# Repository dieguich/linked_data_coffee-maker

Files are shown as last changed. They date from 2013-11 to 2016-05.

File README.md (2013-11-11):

linked_data_coffee-maker
========================

This is a project related to the design of a coffee maker which is able to sense its energy data and to store the breakdown of it in a remote Database as RDF triples. 

Dependencies
-------------

This project has some external dependencies. All of them are stored in other github repositories:

	*  RTClib:     https://github.com/adafruit/RTClib
	*  EmonLib:    https://github.com/openenergymonitor/EmonLib
	*  RestClient: https://github.com/csquared/arduino-restclient
		- This library has been slightly modified, so please use the version which is provided in this github repository.

To add them to you Arduino IDE you have two options: 
	- Either you store them in the libraries folder within the place where you installed the Arduino application; 
	- Either you store them in a folder also called libraries within your Sketchbokk folder.

For more info about new libraries and how to do use of them (dependig of your OS), please follow the next link: http://arduino.cc/en/Guide/Libraries

Thanks a lot to the people who contributes developing libraries like those which are used in this project.

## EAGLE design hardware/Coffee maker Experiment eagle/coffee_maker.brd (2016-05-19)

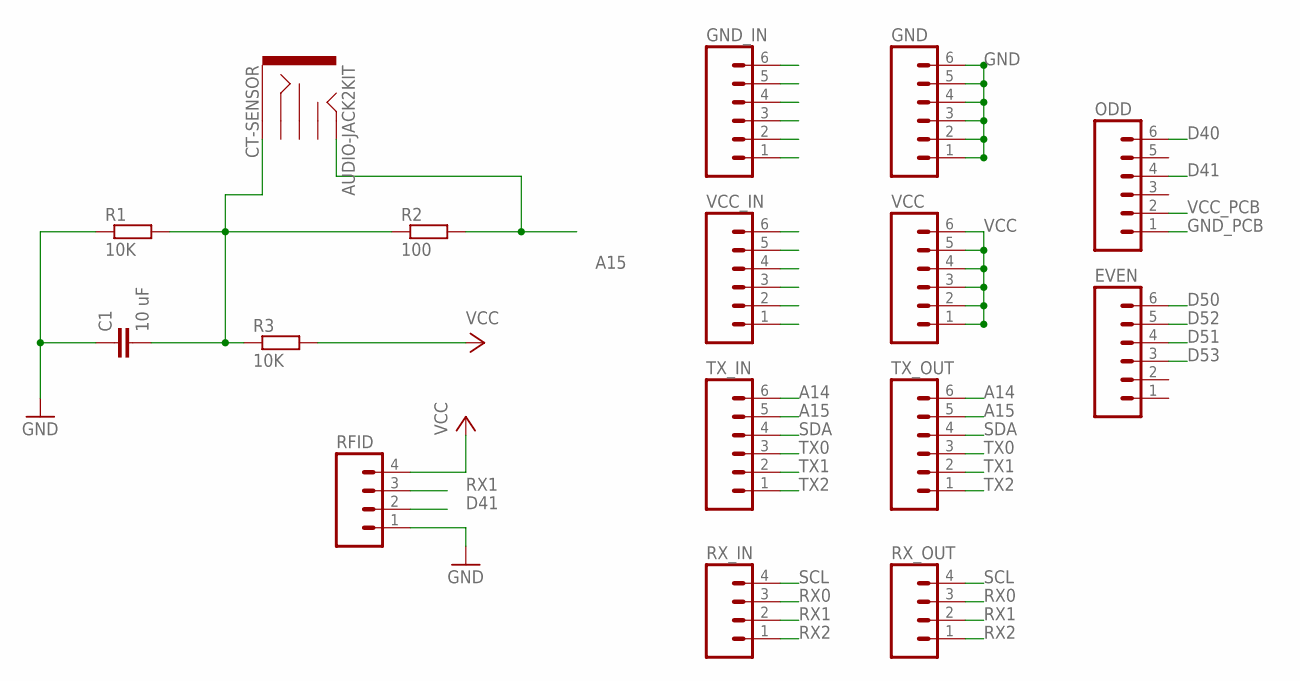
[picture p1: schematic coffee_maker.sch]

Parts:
C1: 10 uF; C1206
CT-SENSOR: AUDIO-JACK2KIT; AUDIO-JACK-KIT
EVEN: M06SIP; 1X06
GND: M06SIP; 1X06
GND_IN: M06SIP; 1X06
ODD: M06SIP; 1X06
R1, R3: 10K; M1206
R2: 100; M1206
RFID: M04SMD2; 1X04-1MM-RA
RX_IN: M04PTH; 1X04
RX_OUT: M04PTH; 1X04
TX_IN: M06SIP; 1X06
TX_OUT: M06SIP; 1X06
VCC: M06SIP; 1X06
VCC_IN: M06SIP; 1X06

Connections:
A14: TX_IN.6, TX_OUT.6
A15: CT-SENSOR.TIP, R2.2, TX_IN.5, TX_OUT.5
D40: ODD.6
D41: ODD.4, RFID.2
D50: EVEN.6
D51: EVEN.4
D52: EVEN.5
D53: EVEN.3
GND: C1.1, GND.1, GND.2, GND.3, GND.4, GND.5, GND.6, GND_IN.6, R1.1, RFID.1
GND_PCB: ODD.1
unnamed: C1.2, CT-SENSOR.SLEEVE, R1.2, R2.1, R3.1
RX0: RX_IN.3, RX_OUT.3
RX1: RFID.3, RX_IN.2, RX_OUT.2
RX2: RX_IN.1, RX_OUT.1
SCL: RX_IN.4, RX_OUT.4
SDA: TX_IN.4, TX_OUT.4
TX0: TX_IN.3, TX_OUT.3
TX1: TX_IN.2, TX_OUT.2
TX2: TX_IN.1, TX_OUT.1
VCC: R3.2, RFID.4, VCC.1, VCC.2, VCC.3, VCC.4, VCC.5, VCC.6, VCC_IN.1
VCC_PCB: ODD.2

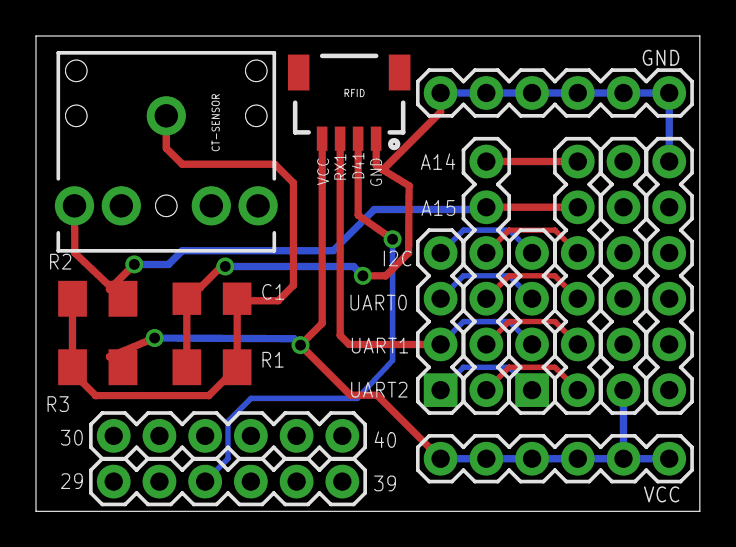
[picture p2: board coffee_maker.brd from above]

Board: 2 copper layers, 36.9 x 26.4 mm, 16 parts (0 on the bottom side), 14 nets.

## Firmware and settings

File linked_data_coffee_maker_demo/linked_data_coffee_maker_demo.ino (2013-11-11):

#include <avr/pgmspace.h>
#include <avr/wdt.h> 
#include <Udp.h>
#include <RTClib.h>
#include <string.h>

#include <SPI.h>
#include <Ethernet.h>
#include <EEPROM.h>
#include <Wire.h>
#include "RestClient.h"
#include "EmonLib.h"
#include "includes.h"

/*  Current */
uint8_t        currentMeasurePin = A1;    // pin to measure the current flow
uint8_t        buttonState       = 0;

/* Time working */
unsigned long currentTime        = 0;        //  to store the current UnixTime in each loop iteration (base: UnixTime + time consumed)
boolean       isStable           = false;

/* Enter a MAC address and IP address for your controller below.
 The IP address will be dependent on your local network:*/
 
/****** TO FILL ******
 ****** ------- ******/
byte mac[]     = {  };  // Type your MAC address inside the curly brackets as following : 0x90, 0xA2, 0xDA, 0x0E, 0x94, 0x69 

/****** TO FILL ******
 ****** ------- ******/
#if STATIC_IP_ADDRESS  
  IPAddress dnsServer(138, 100, 52, 102); // Type your DNS address  inside the brackets as following :    138, 100, 52, 102
  IPAddress gateway(138, 100, 52, 102);   // Type your GATEWAY address inside the brackets as following : 192, 168, 52, 101
  IPAddress netmask(138, 100, 52, 102); // Type your NETMASK address inside the brackets as following :   255, 255, 255, 0
  IPAddress ip(138, 100, 52, 102);      // Type your IP address inside the brackets as following :        192, 168, 52, 102
#endif

/*Related with NTP server and UDP setup for TxRx */
unsigned long UnixTime          = 0;           // variable to store the Unix NTP time retrieved form NTP server
unsigned long referenceUnixTime = 0;           // variable to store the reference Unix NTP time stored in EEPROM (0)

/****** TO FILL ******
 ****** ------- ******/
IPAddress timeServer(129, 6, 15, 28);            // By default Nist server. If you prefer a different UTP server (local or country) change it e.g.: 129, 6, 15, 28


byte pb[NTP_PACKET_SIZE];                      // buffer to hold incoming and outgoing packets 
EthernetUDP Udp;                               // A UDP instance to let us send and receive packets over UDP


EnergyMonitor emonInstance;                    // A emonLib instance to read current Values fron current CT sensor
RestClient client = RestClient(IP_DB_SERVER, PORT_DB_SERVER);  //Rest Client 

/*Energy counters*/
float eCoffees    = 0.0;     // energy Consumption making coffees
float ePeaks      = 0.0;     // energy Consumption by Peaks
float eStartTimes = 0.0;     // energy Consumption by Start Times

/* Counters */
uint8_t nSTimes      = 0;           // number of Start Time peaks per day
uint8_t nCoffees     = 0;           // number of coffees per day
uint8_t nSByPeaks    = 0;           // number of stand by peaks per day
uint8_t nLoopPower   = 0;           // iteration variable


/* Time working */
unsigned long referenceInMillis = 0;        // to store the time stamp when the Energy post was done
unsigned long timeOn            = 0;        // the time that the coffee machine was operating (One hot drink!)
unsigned int  nDays             = 0;        //  number of days the Arduino is active retrying data.


/* Testers */
boolean isStartTime   = false;   // to know if the detected peak belong to [StartTime or Stand-by]
boolean prevWasCoffee = false;   // test if the last peak was a coffe (to distinguish between coffee and peak)
boolean wasOff        = true;    // test if the coffe maker was previously switch off.
boolean isFirstDay    = true;    // variable to know if it's the first day

/*Energy counters*/
float auxEnergy   = 0.0;     // aux to obtain an Energy Consumption making coffees

/* Time working */
unsigned long countStart        = 0;        // to count when a peak has started

/* NoSQL DataBase */
String response   = "";
char   postData[400];
char   buffer[30];
char   consumptionSecsDB[10]; 
char   consumptionTypeDB[20];

/* RFID tags */
char tagValue[10];
long timeRfidDetected = 0;


/* LEDs to know the status */
uint8_t readyPin = 7;
uint8_t postPin  = 3;

/**********
  SETUP
***********/
void setup() {
   
   Serial3.begin(9600);
   wdt_disable(); 
#if ECHO_TO_SERIAL  
   Serial.begin(9600); 
   Serial.println("Start");
#endif
    
    pinMode(readyPin, OUTPUT);
    pinMode(postPin,  OUTPUT);
    pinMode(currentMeasurePin, INPUT);                    // sets the analog pin as input (current measure throug the coffe machine plug -mains)*/    
    digitalWrite(readyPin,  LOW);
    digitalWrite(postPin,   LOW);    
   
   #if STATIC_IP_ADDRESS 
     Ethernet.begin(mac, ip, dnsServer, gateway, netmask);  
   #else
     Ethernet.begin(mac);  
   #endif
   delay(100);
   
   getUnixTime();
#if ECHO_TO_SERIAL  
  Serial.println(Ethernet.localIP()); 
  Serial.print("UnixTime provided by the UTP: ");  
  Serial.println(UnixTime);
  Serial.print("UnixTime converted in human readable time: ");    
  Serial.println(printDateTime(UnixTime));
#endif 

  referenceUnixTime = UnixTime;
  
#if ECHO_TO_SERIAL  
   Serial.println("Working");
#endif
  
  emonInstance.current(currentMeasurePin, CALIBRATION); // sets the Pin from and the calibration to read current Values.
  referenceInMillis = millis();                         // timeStamp to know when the current program start.
  wdt_enable(WDTO_8S);
  
  digitalWrite(readyPin, HIGH);
}

/***********
  LOOP
************/
void loop() {
   
  wdt_reset(); 
  currentTime = UnixTime + ((millis()-referenceInMillis)/1000);
  delay(25);
  
  float currentToMeasure = emonInstance.calcIrms(EMON_INSTANCE_VALUE);
  if (isStable == false && currentToMeasure < 0.1){
    isStable = true;
  }
  if (isStable){
   controlCoffeMade(currentToMeasure); // to read the the RMS current flow [0..30A]
   if (Serial3.available() > 0) {
     rfidReadMug();
   }
   else if(!prevWasCoffee && (millis() > timeRfidDetected + 120000)){
     memset(tagValue, '\0', 10);
   }
  }
}

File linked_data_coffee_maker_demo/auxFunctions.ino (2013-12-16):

/**
  calls the function to show and compute consumptions

**/

void accumulatedEnergyByPeak(){
  
  switch (setType()){
    case 1:{
      eCoffees += (auxEnergy/nLoopPower)*(timeOn/3600000.0);
  #if ECHO_TO_SERIAL                                             
      Serial.print("Consumed by Coffees: ");
      Serial.println(eCoffees, 2);
  #endif                    
      break;
    }
    case 2:{      
      eStartTimes += (auxEnergy/nLoopPower)*(timeOn/3600000.0);
  #if ECHO_TO_SERIAL                                                         
      Serial.print("Consumed by S. time: ");
      Serial.println(eStartTimes, 2);
  #endif            
      break;
    }
    case 3:{
      ePeaks += (auxEnergy/nLoopPower)*(timeOn/3600000.0);
  #if ECHO_TO_SERIAL                                                         
      Serial.print("Consumed by Peaks: ");
      Serial.println(ePeaks, 2);
  #endif            
      break;
    }
    //default: Serial.println("No type");
  }    
}



/**
  This function is many fold:
    * It figures out if the detected activation is a Stand By Peak, a Start Time or a Coffee.
    * Print this information in Serial output if DEBUG mode activated and to currentFile.
    * Before return the current Type, it prints the time implied in each of the detected activation.
**/
int setType(){

  uint8_t nType = 0;

  if(isStartTime){
    if(wasOff){
      wasOff = false;
      nSTimes++;
      prevWasCoffee = false;        
      nType = 2;           
      prinFromMemorySerial(sTime);         
    }
    else if(millis() < countStart){
      if(timeOn > 12000){    
        prinFromMemorySerial(coffee);
        nCoffees++;
        prevWasCoffee = true;
        isStartTime = false;
        nType = 1;
      }else{  
        prinFromMemorySerial(sTime);               
        nSTimes++;
        prevWasCoffee = false;        
        nType = 2;
      }
    }
    else{
      isStartTime = false;
      if(timeOn > 7000 && !prevWasCoffee){
        prinFromMemorySerial(coffee);
        prevWasCoffee = true;
        nCoffees++;
        nType = 1;         
      }else{      
        prinFromMemorySerial(peak);   
        nSByPeaks++;
        prevWasCoffee = false;        
        nType = 3;
      }
    }
  }
  else if(timeOn > 7000){  // if the operating time is bigger than 7secs is a coffee REMOVED:  && !prevWasCoffee
    prinFromMemorySerial(coffee);
    prevWasCoffee = true;    
    nCoffees++;
    nType = 1;
  }
  else{
    prinFromMemorySerial(peak);
    nSByPeaks++;
    prevWasCoffee = false;            
    nType = 3;
  }
  memset(consumptionSecsDB, '\0', 10);
  floatToString(consumptionSecsDB, (timeOn/1000.0), 2, 3);
#if ECHO_TO_SERIAL
  Serial.print(timeOn);
  Serial.print('|');    
#endif

 return nType;
}

/**
  Function to print error to the Serial output (if DEBUG mode is activated).
  Also sets a led to HIGH if an error has been triggered
**/
void error(char *str)
{
#if ECHO_TO_SERIAL    
  Serial.print("error: ");
  Serial.println(str);
#endif   
  delay(500);  
}

/**
  float to string conversion function that runs standalone
**/
char * floatToString(char * outstr, double val, byte precision, byte widthp){
  char temp[16];
  byte i;

  // compute the rounding factor and fractional multiplier
  double roundingFactor = 0.5;
  unsigned long mult = 1;
  for (i = 0; i < precision; i++)
  {
    roundingFactor /= 10.0;
    mult *= 10;
  }
  
  temp[0]='\0';
  outstr[0]='\0';

  if(val < 0.0){
    strcpy(outstr,"-\0");
    val = -val;
  }

  val += roundingFactor;

  strcat(outstr, itoa(int(val),temp,10));  //prints the int part
  if( precision > 0) {
    strcat(outstr, ".\0"); // print the decimal point
    unsigned long frac;
    unsigned long mult = 1;
    byte padding = precision -1;
    while(precision--)
      mult *=10;

    if(val >= 0)
      frac = (val - int(val)) * mult;
    else
      frac = (int(val)- val ) * mult;
    unsigned long frac1 = frac;

    while(frac1 /= 10)
      padding--;

    while(padding--)
      strcat(outstr,"0\0");

    strcat(outstr,itoa(frac,temp,10));
  }

  // generate space padding
  if ((widthp != 0)&&(widthp >= strlen(outstr))){
    byte J=0;
    J = widthp - strlen(outstr);
    
    for (i=0; i< J; i++) {
      temp[i] = ' ';
    }

    temp[i++] = '\0';
    strcat(temp,outstr);
    strcpy(outstr,temp);
  }
  return outstr;
} 

/*****
CouchDB
*****/
void POSTrequest(char* deviceID, char* device_type, char* date, char* timeSecs, char* consumption_type, char* consumption_time_in_secs, char* energy_consumption_Wh, char* coffeeMugID){

    memset(postData, '\0', 400);
    strcpy_P(buffer, (char*)pgm_read_word(&(json_properties[0])));
    strcat(postData, buffer);
    strcat(postData, deviceID);
    strcpy_P(buffer, (char*)pgm_read_word(&(json_properties[1])));
    strcat(postData, buffer);
    strcat(postData, device_type);
    strcpy_P(buffer, (char*)pgm_read_word(&(json_properties[2])));
    strcat(postData, buffer);
    strcat(postData, date);
    strcpy_P(buffer, (char*)pgm_read_word(&(json_properties[3])));
    strcat(postData, buffer);
    strcat(postData, timeSecs);    
    strcpy_P(buffer, (char*)pgm_read_word(&(json_properties[4])));
    strcat(postData, buffer);
    strcat(postData, consumption_type);
    strcpy_P(buffer, (char*)pgm_read_word(&(json_properties[5])));
    strcat(postData, buffer);
    strcat(postData, consumption_time_in_secs);
    strcpy_P(buffer, (char*)pgm_read_word(&(json_properties[6])));
    strcat(postData, buffer);
    strcat(postData, energy_consumption_Wh);
    strcpy_P(buffer, (char*)pgm_read_word(&(json_properties[7])));
    strcat(postData, buffer);
    strcat(postData, coffeeMugID);    
    strcpy_P(buffer, (char*)pgm_read_word(&(json_properties[8])));
    strcat(postData, buffer);
    

    int statusCode = client.post("/", postData, &response);
    //int statusCode = 1;
    #if ECHO_TO_SERIAL  
      Serial.println(postData);
      Serial.print("Status code from server: ");
      Serial.println(statusCode);
      Serial.print("Response body from server: ");
      Serial.println(response);
    #endif
   
    memset(postData, '\0', 400);
    memset(buffer, '\0', 30);
    response = "";  
}


/**
 To Read the tag RFID
**/
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

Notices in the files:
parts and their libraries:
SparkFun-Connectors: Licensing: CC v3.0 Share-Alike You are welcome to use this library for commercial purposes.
